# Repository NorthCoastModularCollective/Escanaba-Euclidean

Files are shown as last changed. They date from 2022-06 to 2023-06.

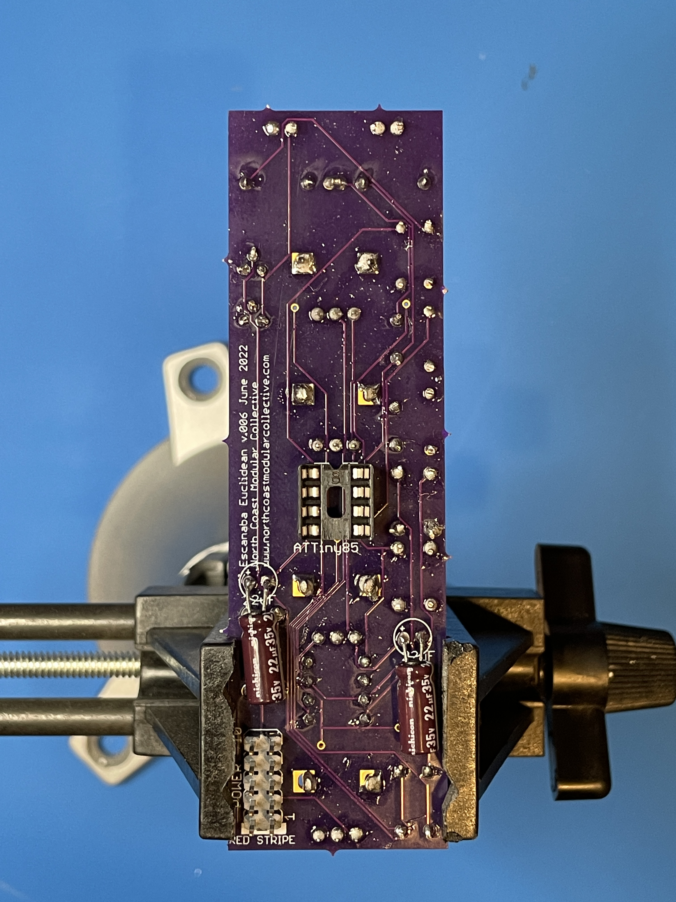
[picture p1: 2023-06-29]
build_guide/IMG_0187.JPG

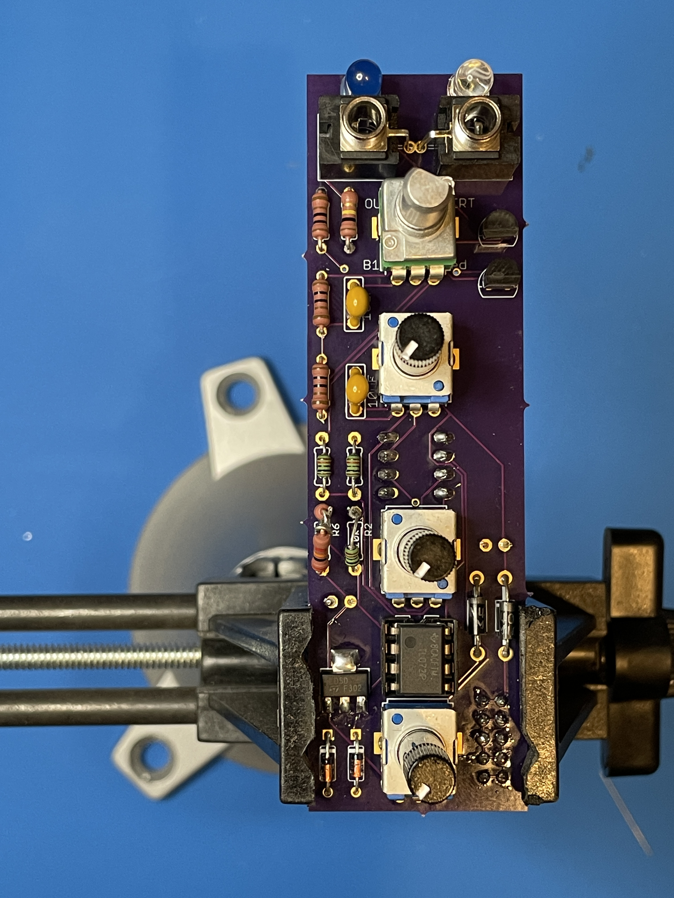
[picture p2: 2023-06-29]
build_guide/IMG_0186.JPG

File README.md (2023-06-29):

# EuclideanTrigger
A simple module, based on the ATtiny85 that creates euclidean beats from a clock input. [under development]

The Escanaba Euclidean module has 3 alternate firmware modes:
## Escanaba Euclidean Firmware 
The Eucliean firmware generates euclidean rhythms synchronized to an external eurorack clock source. If no clock source is available it will self clock. Its 3 controls are as follows: 
- Number of hits
- Length of pattern in beats
- Pattern rotation. 
When in self clocking mode, the rotation control becomes a tempo control. 
## Calumet Clock Firmware
The Calument Clock firmware turns the module into a eurorack clock source. Its 3 controls are as follows:
- Swing control
- Clock Division/Multiplication
- Tempo
## Burst Generator
The Burst Generator firmware allows the module to respond to incoming trigger signals by repeating them in a variety of ways. This allows the creation of "bouncing ball" rhythms, ratchets, and other rhythmic tricks. Its controls are as follows:
- Number of repeats
- Initial repeat speed
- A "gravity" control that controls whether the repeats accelerate or decelerate in speed.

# Build instructions

[How to build the hardware](https://github.com/NorthCoastModularCollective/Escanaba-Euclidean/wiki/Build-Instructions)

# How To Setup Firmware

1. In the Arduino editor, in the tools menu, set the board to "AtTiny25/45/85"
2. In the Arduino editor, go to Sketch->Include Library->add .zip library and then select the lib folder from the project root.
3. set Processor to "AtTiny85"
4. set Clock to "Internal 16Mhz"
6. plug your programmer into a usb port. We reccomend the (TinyAvr programmer)[https://www.sparkfun.com/products/11801] from sparkfun
7. select your programmer in the tools menu (USBTinyISP if using the TinyAvr programmer - Note: Windows needs a driver for this to work)
8. in tools, select burn bootloader. Your AtTiny is now configured to run at 16Mhz.
9. now hit the upload button in the arduino editor to flash the firmware. (Note: if you're on a Mac, select "Sketch > Upload Using Programmer" because the upload button may throw an error about no programmer being available)
10. place the chip into the mount on the back of the module. Take care to make sure the dot on the back of the chip aligns with the indent on the PCB board diagram.
11. plug the module into your rack and have fun!

# License
All works are [CC BY NC](https://creativecommons.org/licenses/by-nc/4.0/) unless otherwise specified.

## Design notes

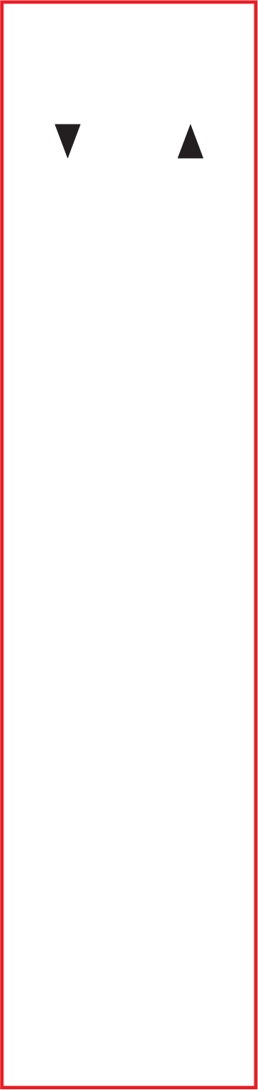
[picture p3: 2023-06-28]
hardware/panels/v12/euclidean panel v12 DiffusionLabels.BMP

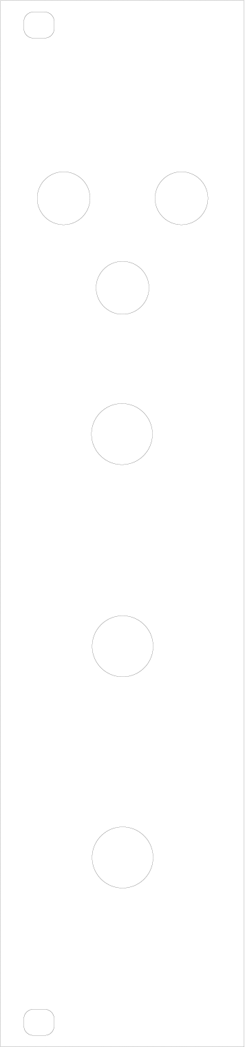
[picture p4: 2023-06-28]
hardware/panels/v12/euclidean panel v12 DrillHoles.png

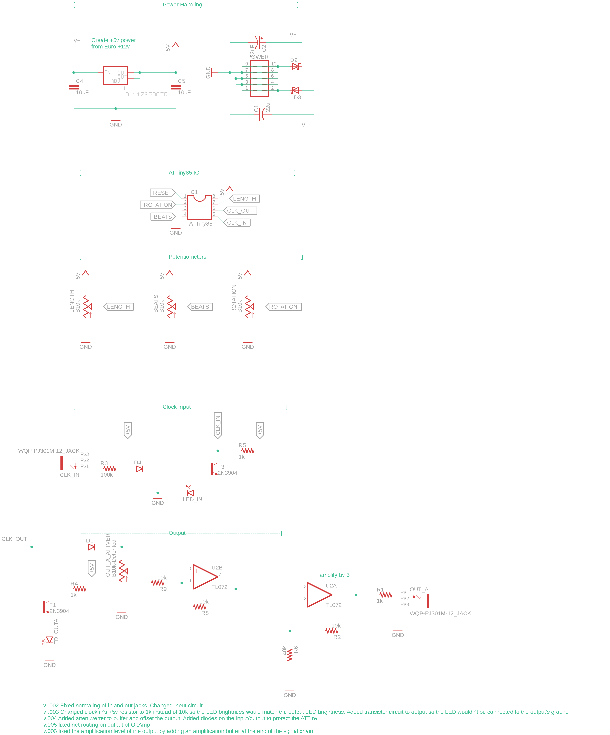
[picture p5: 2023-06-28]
hardware/PCB/Schematic.png

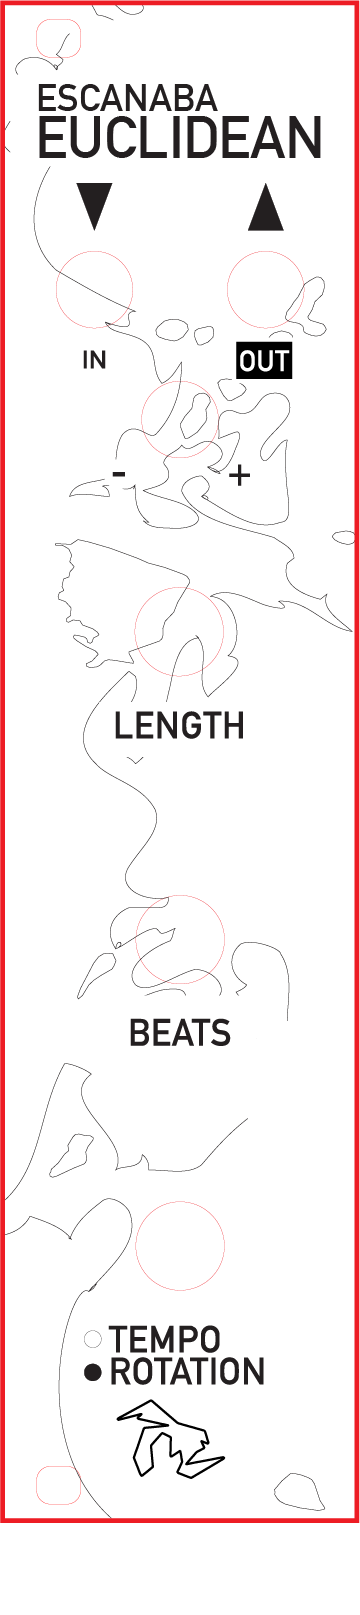
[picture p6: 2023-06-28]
hardware/panels/Escanaba Euclidean/euclidean panel v13 REFERENCE.BMP

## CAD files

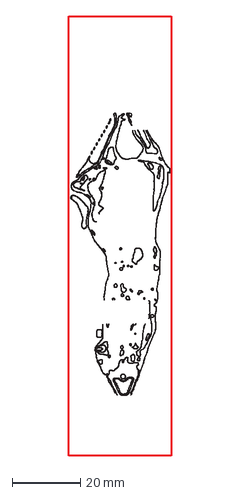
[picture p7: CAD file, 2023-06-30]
hardware/panels/Belle Isle Burst/Belle Isle Burst panel v12 TOPO LINES.dxf
30.0 x 128.5 mm

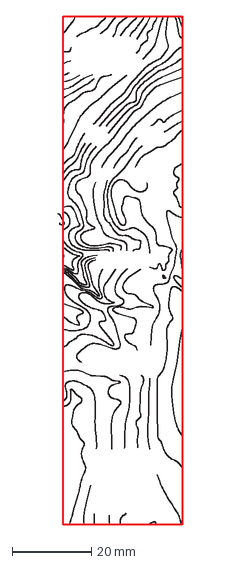
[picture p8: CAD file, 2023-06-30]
hardware/panels/Calumet Clock/Calumet Clock panel v12 TOPO LINES.dxf
31.3 x 128.5 mm

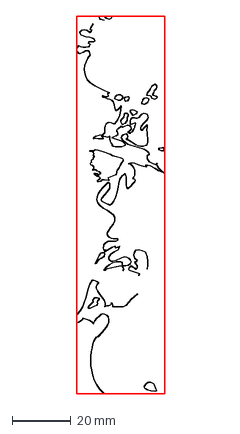
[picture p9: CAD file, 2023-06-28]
hardware/panels/v12/euclidean panel v12 TopoLines.dxf
30.5 x 128.5 mm

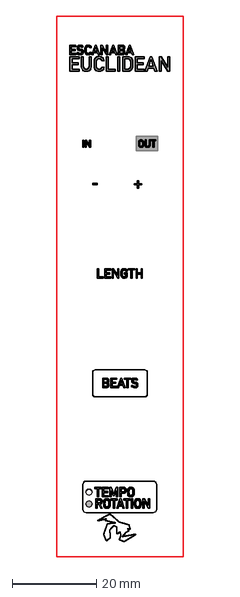
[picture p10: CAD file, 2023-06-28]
hardware/panels/v12/euclidean panel v12 PanelGraphics v2.dxf
30.0 x 128.5 mm

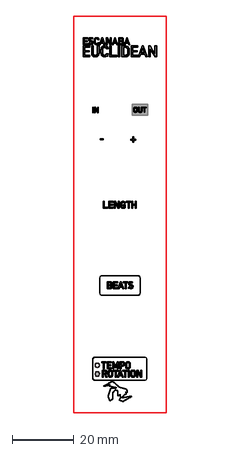
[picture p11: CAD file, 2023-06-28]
hardware/panels/v12/euclidean panel v12 PanelGraphics.dxf
30.0 x 128.5 mm

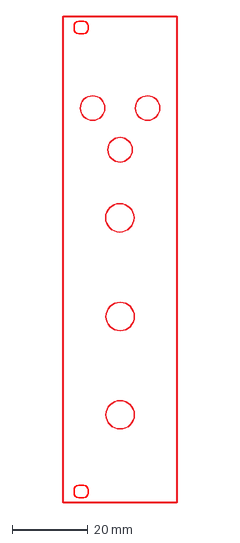
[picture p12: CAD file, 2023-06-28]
hardware/panels/v12/euclidean panel v12.dxf
30.0 x 128.5 mm

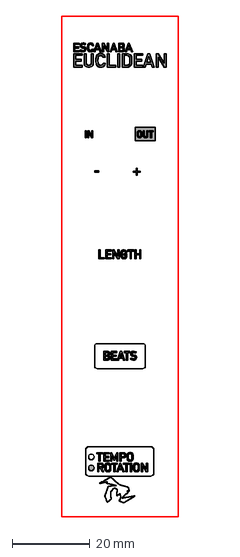
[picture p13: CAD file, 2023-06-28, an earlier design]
hardware/panels/Escanaba Euclidean/old versions/v12/euclidean panel v12.dxf
30.0 x 128.5 mm

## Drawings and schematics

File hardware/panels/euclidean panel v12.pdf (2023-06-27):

## EUCLIDEAN

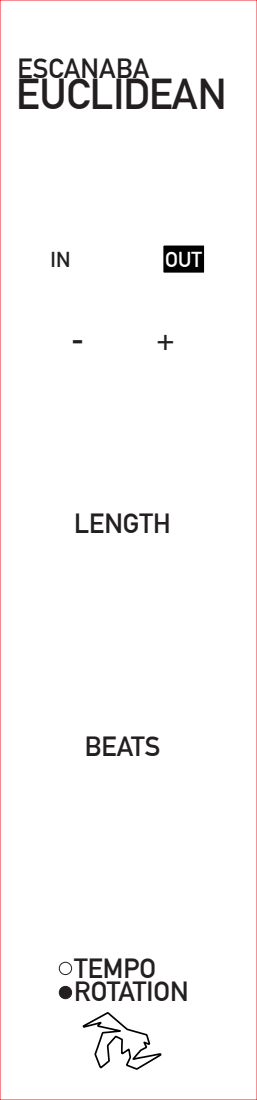
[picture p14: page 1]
OUT; LENGTH; BEATS; ROTATION; TEMPO; ESCANABA

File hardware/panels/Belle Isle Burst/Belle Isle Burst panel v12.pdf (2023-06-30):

## BURST

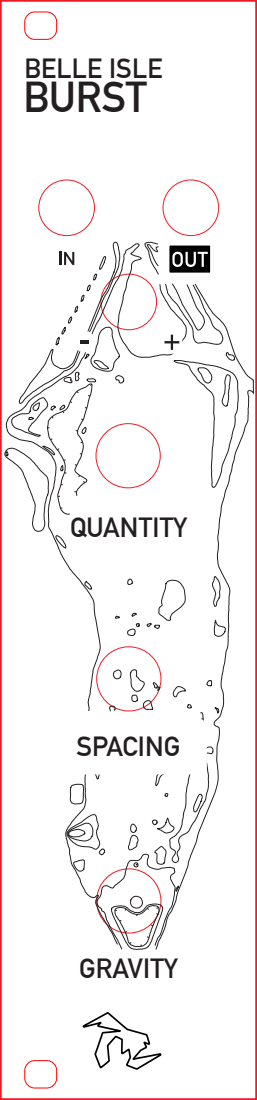
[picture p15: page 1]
QUANTITY; SPACING; GRAVITY; BELLE ISLE

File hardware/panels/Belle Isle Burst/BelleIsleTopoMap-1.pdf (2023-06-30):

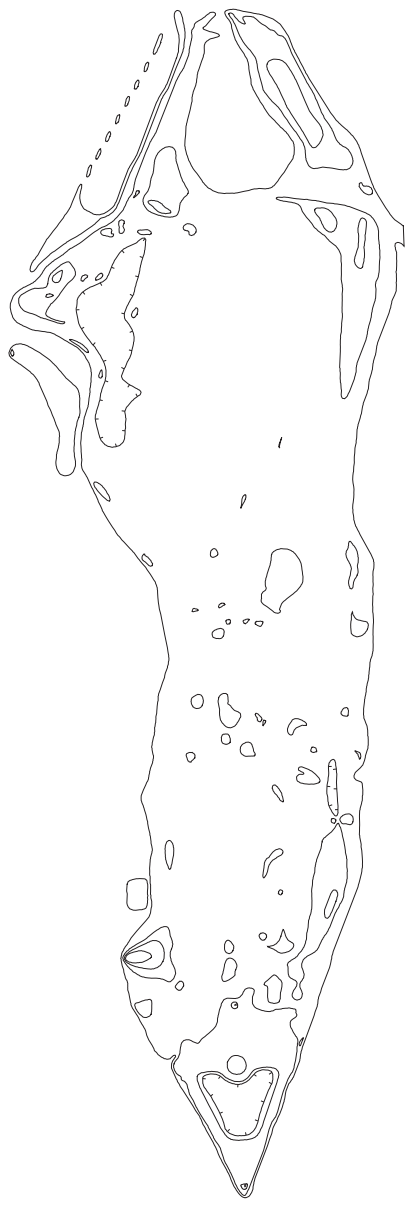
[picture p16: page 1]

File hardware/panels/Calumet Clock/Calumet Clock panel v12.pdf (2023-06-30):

## CLOCK

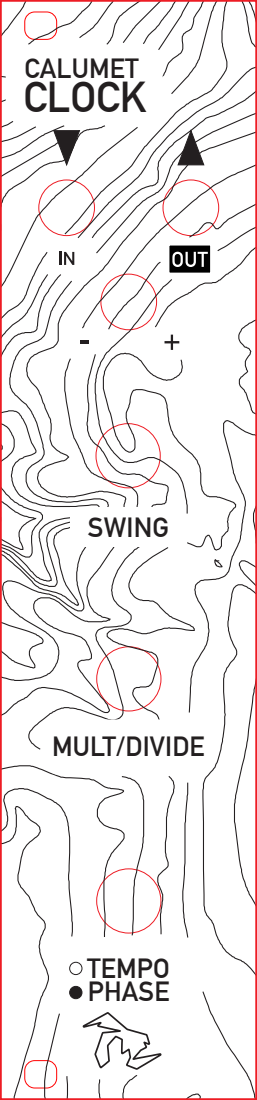
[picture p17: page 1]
SWING; MULT/DIVIDE; PHASE; TEMPO; CALUMET

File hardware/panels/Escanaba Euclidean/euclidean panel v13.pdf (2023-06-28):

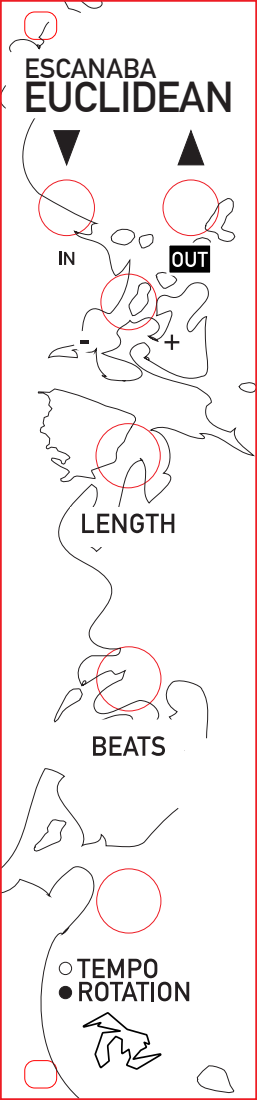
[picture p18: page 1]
ESCANABA EUCLIDEAN

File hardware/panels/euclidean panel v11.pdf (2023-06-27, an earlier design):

## EUCLIDEAN

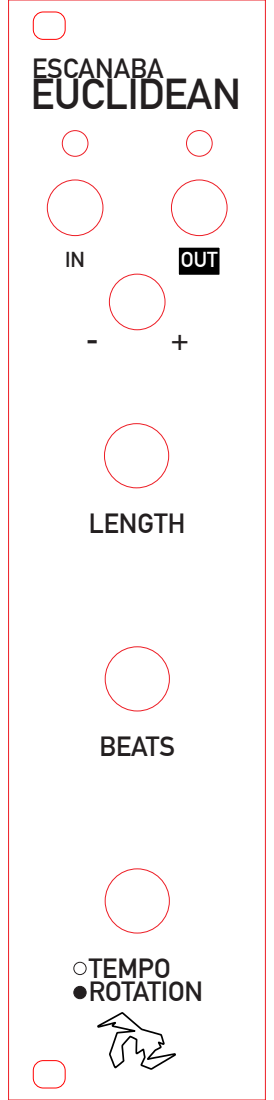
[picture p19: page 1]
OUT; LENGTH; BEATS; ROTATION; TEMPO; ESCANABA

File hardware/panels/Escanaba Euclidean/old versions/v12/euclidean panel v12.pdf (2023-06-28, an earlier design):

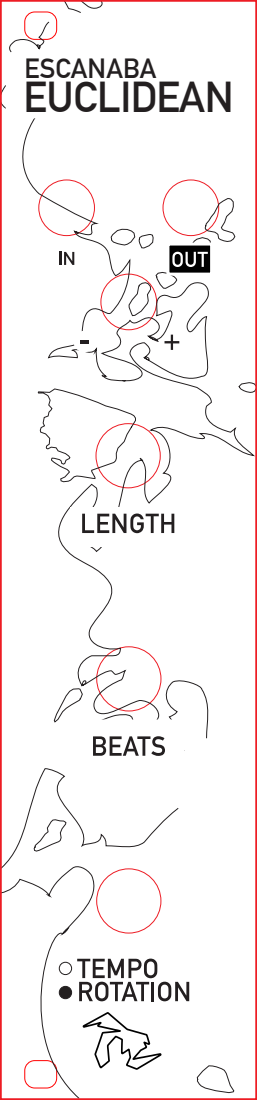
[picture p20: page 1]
ESCANABA EUCLIDEAN

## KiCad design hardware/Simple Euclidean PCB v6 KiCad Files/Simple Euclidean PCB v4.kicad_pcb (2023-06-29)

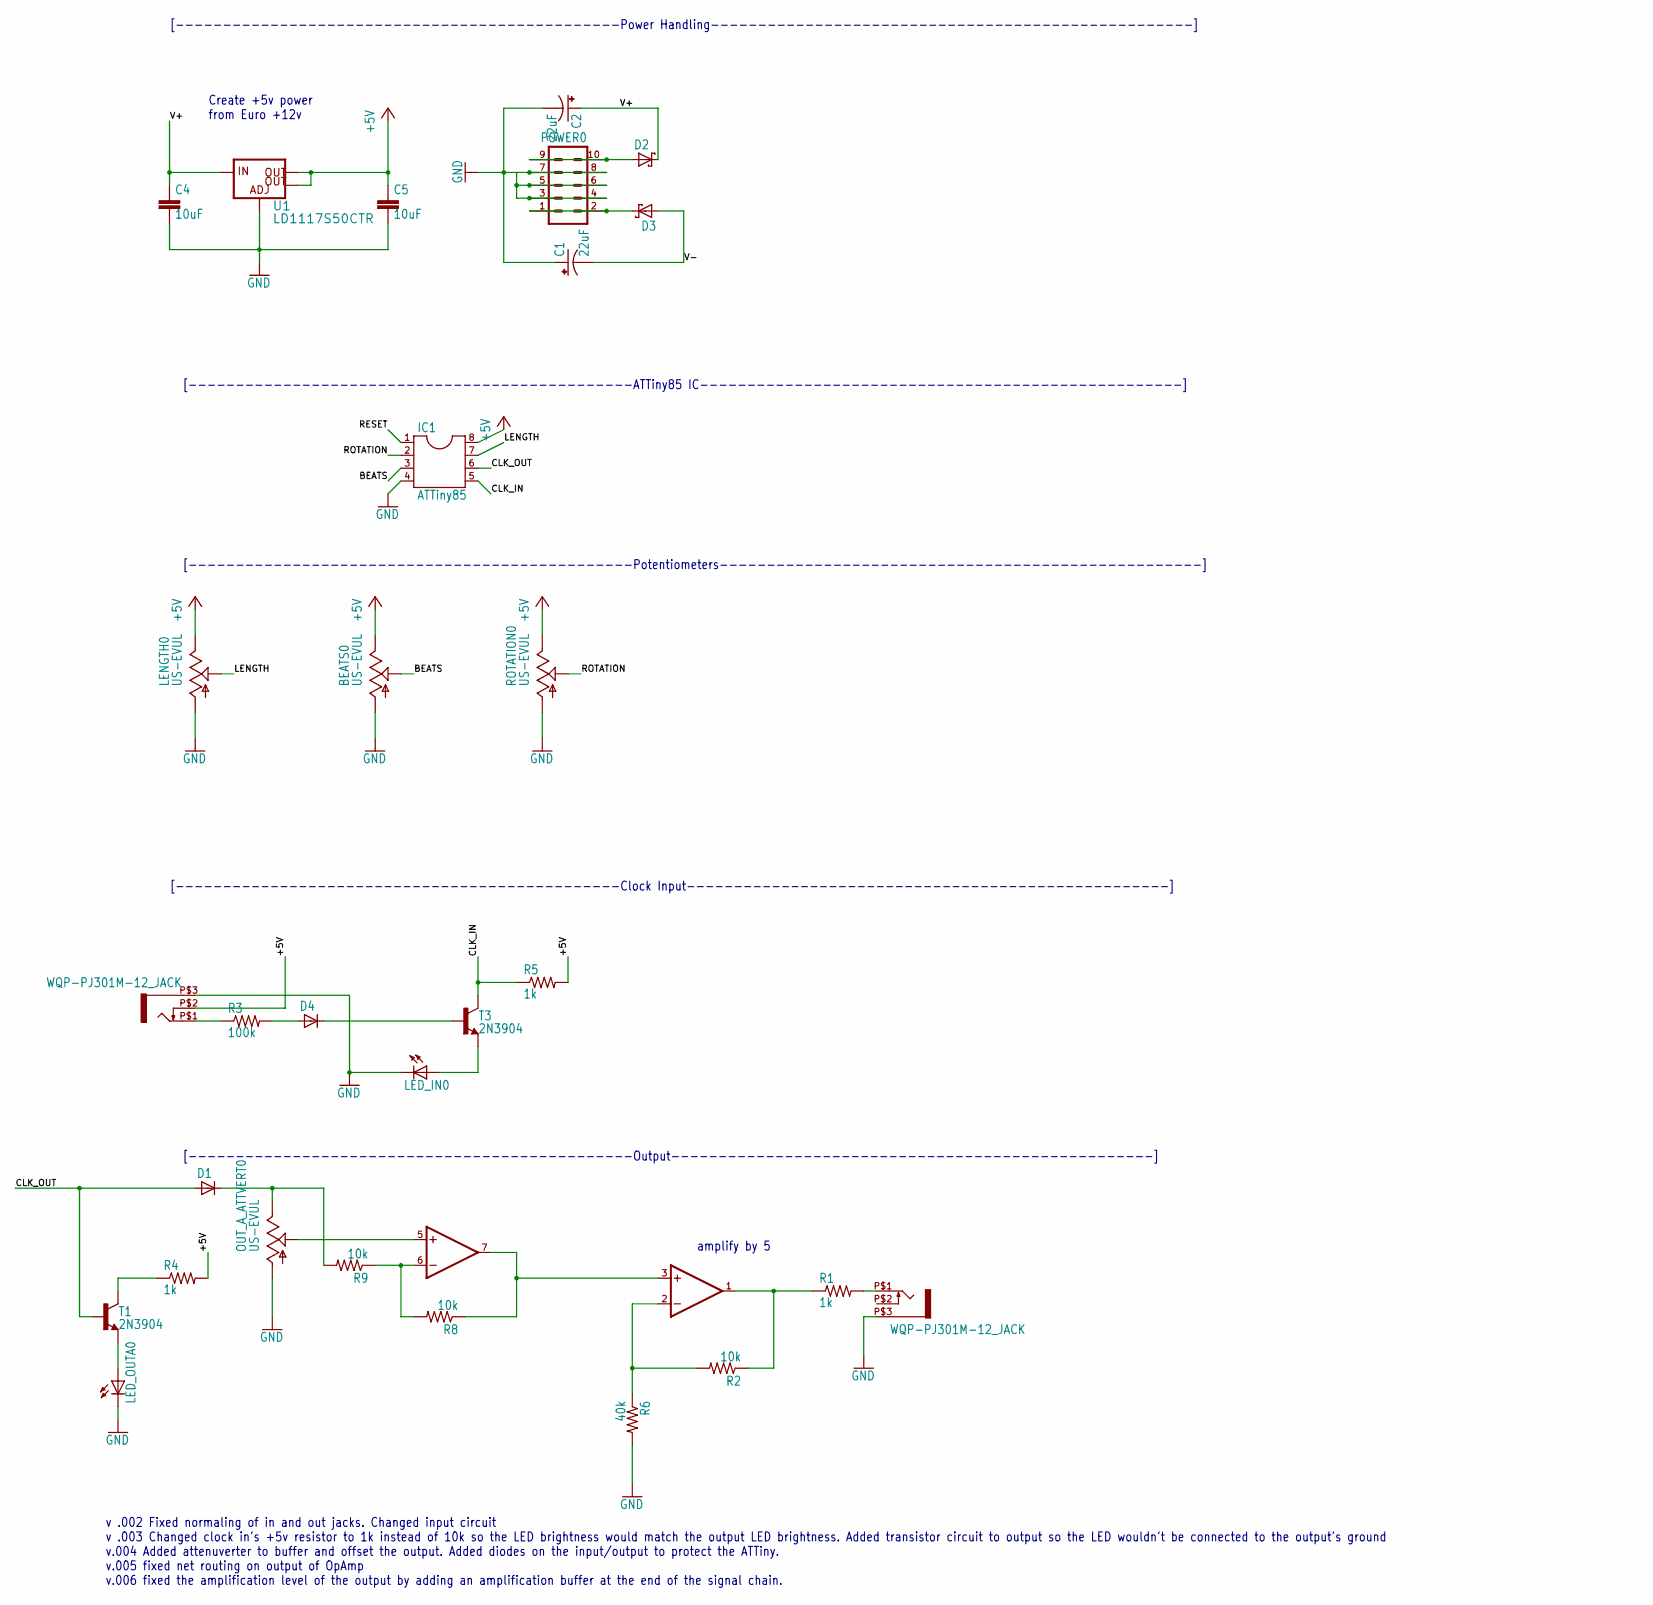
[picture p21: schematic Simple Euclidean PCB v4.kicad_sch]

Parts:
BEATS0: US-EVUL; EVUFXL
C1, C2: 22uF; E2,5-5
C4, C5: 10uF; C5B2.5
CLK_IN0: WQP-PJ301M-12_JACK
D1, D4: SMALL_DIODEDO35-7; DO35-7
D2, D3: SCHOTTKY-DIODEDO41; DO41-10
IC1: ATTiny85; DIL08
LED_IN0: LED3MM
LED_OUTA0: LED3MM
LENGTH0: US-EVUL; EVUFXL
OUT_A0: WQP-PJ301M-12_JACK
OUT_A_ATTVERT0: US-EVUL; EVUFXL
POWER0: MA05-2
R1, R4, R5: 1k; 0204_7
R2, R8, R9: 10k; 0204_7
R3: 100k; 0204_7
R6: 40k; 0204_7
ROTATION0: US-EVUL; EVUFXL
T1, T3: 2N3904; TO92
U1: LD1117S50CTR; SOT223
U2: TL072; DIL08-SML

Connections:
+5V: BEATS0.3 (E), C5.1, CLK_IN0.P$2 (3), IC1.8, LENGTH0.3 (E), R4.2, R5.2, ROTATION0.3 (E), U1.2 (OUT), U1.4 (OUT@1)
BEATS: BEATS0.2 (S), IC1.3
CLK_IN: IC1.5, R5.1, T3.1 (C)
CLK_IN1: R4.1, T1.1 (C)
CLK_OUT: D1.A, IC1.6, T1.2 (B)
GND: BEATS0.1 (A), C1.+, C2.-, C4.2, C5.2, CLK_IN0.P$3 (1), IC1.4, LED_IN0.K (C), LED_OUTA0.K (C), LENGTH0.1 (A), OUT_A0.P$3 (1), OUT_A_ATTVERT0.1 (A), POWER0.3, POWER0.4, POWER0.5, POWER0.6, POWER0.7, POWER0.8, R6.2, ROTATION0.1 (A), U1.1 (ADJ)
LENGTH: IC1.7, LENGTH0.2 (S)
unnamed: CLK_IN0.P$1 (2), R3.1
unnamed: OUT_A0.P$1 (2), R1.2
unnamed: D1.C, OUT_A_ATTVERT0.3 (E), R9.2
unnamed: D4.C, T3.2 (B)
unnamed: D4.A, R3.2
unnamed: LED_IN0.A, T3.3 (E)
unnamed: LED_OUTA0.A, T1.3 (E)
unnamed: R1.1, R2.1, U2.1 (OUT)
unnamed: R2.2, R6.1, U2.2 (-IN)
unnamed: OUT_A_ATTVERT0.2 (S), U2.5 (+IN)
unnamed: R8.2, R9.1, U2.6 (-IN)
unnamed: D2.A, POWER0.9, POWER0.10
unnamed: D3.C, POWER0.1, POWER0.2
OPAMPOUT: R8.1, U2.3 (+IN), U2.7 (OUT)
RESET: IC1.1
ROTATION: IC1.2, ROTATION0.2 (S)
V+: C2.+, C4.1, D2.C, U1.3 (IN), U2.8 (V+)
V-: C1.-, D3.A, U2.4 (V-)

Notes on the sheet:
amplify by 5
v .002 Fixed normaling of in and out jacks. Changed input circuit v .003 Changed clock in's +5v resistor to 1k instead of 10k so the LED brightness would match the output LED brightness. Added transistor circuit to output so the LED wouldn't be connected to the output's ground v.004 Added attenuver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
[-----------------------------------------------ATTiny85 IC---------------------------------------------------]
Create +5v power from Euro +12v
[-----------------------------------------------Clock Input---------------------------------------------------]
[-----------------------------------------------Power Handling---------------------------------------------------]
[-----------------------------------------------Output---------------------------------------------------]
[-----------------------------------------------Potentiometers---------------------------------------------------]

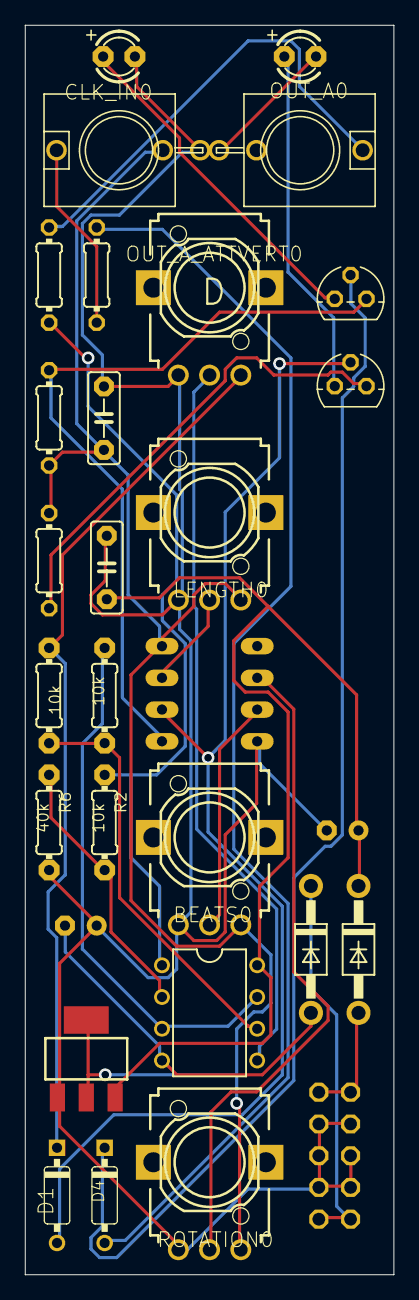
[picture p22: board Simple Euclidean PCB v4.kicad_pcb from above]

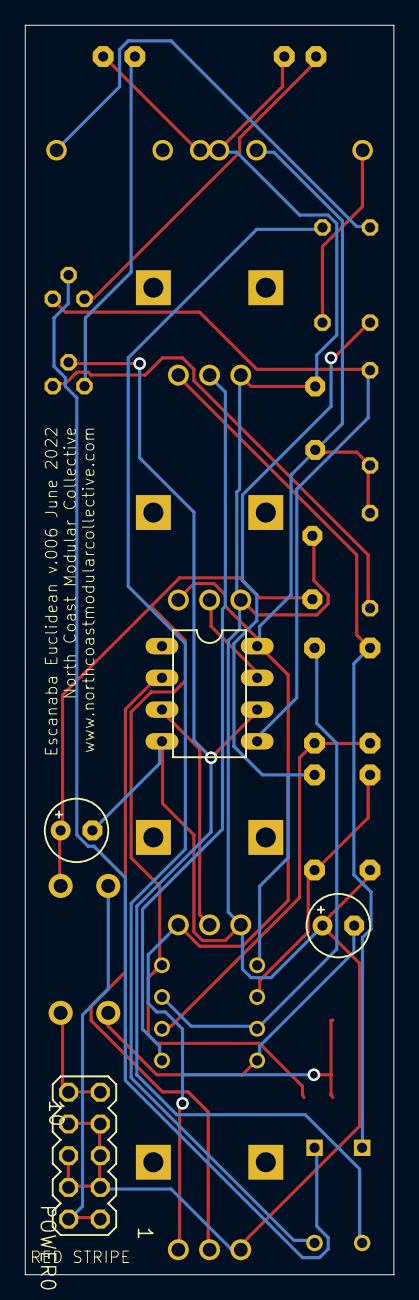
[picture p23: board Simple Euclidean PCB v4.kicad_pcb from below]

Board: 2 copper layers, 29.5 x 100.0 mm, 30 parts (4 on the bottom side), 24 nets.

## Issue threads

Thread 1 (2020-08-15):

Clock out fires a trigger on module power up

joebauer, 2020-08-15:
For some reason the module sends a trig as it is powering on. Make it so no voltages come out of the clock out unless there is a valid clock in, or unless the module is in internal clocking mode.

Note: The led output jack is normalize to the positive lead rather than the negative... verify that this is not a hardware issue.

billvanloo, 2024-01-03:
Nick and I tested this today via Zoom. We observed the following behavior:

1. When power is applied to the system, the Clock module produces at least one pulse immediately. We sometimes observed it sending out two pulses, but it was hard to distinguish whether this was based on the clock tempo or just random pulses.
2. Clock seems to immediately start up in internally clocked mode, and starts generating pulses right away at the determined clock rate.

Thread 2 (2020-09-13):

Clock output LED is dim when jack connected

joebauer, 2020-09-13:

billvanloo, 2024-01-03:
I can't reproduce this with either the Calumet Clock or Euclidean firmwares running on 2 separate builds of the modules. I think this was fixed.

Closed 2024-01-03.

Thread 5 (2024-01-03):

Internal/External Clock Modes not yet implemented

billvanloo, 2024-01-03:
Based on our observations during testing, as well as looking at the source code for Calumet Clock, @thynk and I determined that the code to switch between internal and external clock modes is not yet implemented.

There are variables defined for configuration:

const milliseconds TIME_UNTIL_INTERNAL_CLOCK_MODE = 4000;
const ClockMode CLOCK_MODE_ON_STARTUP = internal;

These don't appear anywhere else in the code yet, however. That is, there's no check that uses the TIME_UNTIL_INTERNAL_CLOCK_MODE to determine when it should switch from externally clocked to internally clocked mode, and nothing that uses the ClockMode variable to switch between internal and external.

billvanloo, 2024-01-03:
This appears to be implemented in the Euclidean firmware; there is a clockMode variable defined in Euclidean that is then used in a switch statement to determine in which mode to operate. This should probably just be copied over to Clock:

https://github.com/NorthCoastModularCollective/Escanaba-Euclidean/blob/master/EscansabaEuclidean/

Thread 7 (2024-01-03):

Output voltage too low to trigger LPG

billvanloo, 2024-01-03:
The output voltage of Clock and Euclidean is too low to correctly trigger the LPG, while the output voltage of Pam's triggers LPG correctly.

During Zoom testing today, @thynk and I observed the following:

1. Both Clock and Euclidean produced output voltages for their trigger signals in the range of -3.4V to +3.4V. Photos of the scope below.

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

2. The attenuverter works correctly, with the center detent measuring almost exactly 0V (we measured between 0.02 and 0.03V).

3. By comparison, the output from Pamela's New Workout, set to 100% level, produces a voltage of around 4.1-4.9V. Photo of the scope below.

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

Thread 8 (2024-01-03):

Output LED does not dim in proportion to attenuverter setting

billvanloo, 2024-01-03:
@thynk and I observed during testing that the output LED does not dim when the attenuverter control is adjusted. The output LED is a consistent brightness value regardless of the attenuverter's setting.

From a user perspective, it would be nice if the LED brightness was proportional to the attenuverter's setting, to show that the output signal is being reduced in level. This would probably require a bipolar LED to allow the inverted voltage to still power it correctly, which might mean a hardware revision.

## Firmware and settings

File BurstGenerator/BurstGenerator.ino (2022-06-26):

#include <clock_core.h>
#include <tuple.h>
#include <euclid_core.h>
/* CONFIG */
const milliseconds PULSE_WIDTH = 10;
const milliseconds TIME_UNTIL_INTERNAL_CLOCK_MODE = 4000;
const ClockMode CLOCK_MODE_ON_STARTUP = internal; //module starts up in internal clock mode... change this line to default the clock mode to external if needed
const unsigned short MAX_BEATS_IN_BAR = 16;

/* HARDWARE */
const int triggerOutPin           = 1;
const int triggerInPin            = 0;
const int numberOfRepeatsKnobPin  = A1;
const int spacingKnobPin          = A2;
const int gravityKnobPin          = A3;

/* GLOBAL STATE */
milliseconds timeOfLastTriggerInChange;
milliseconds timeOfLastPulseOut;
bool previousTriggerInputState = false;
unsigned int numberOfRepeatsCounter = 0;
unsigned long timeOfNextTriggerInMillis = 200;
bool isBursting = false;
unsigned int numberOfRepeats=0;
unsigned int spacingInMillis=0;


/* SHELL (global state and run loop) */
void setup()
{
  pinMode(triggerOutPin, OUTPUT);
  pinMode(triggerInPin, INPUT);
  digitalWrite(triggerOutPin, LOW);

}

void loop()
{
  const auto currentTime = millis();
  
  const unsigned int initialSpacingInMillis = readSpacingInput();
  const bool stateOfTriggerInPin = readTriggerInput();
  const float gravity = readGravityInput();
  const auto hasNewTriggerIn = detectNewRisingClockEdge(stateOfTriggerInPin, previousTriggerInputState); 
  bool shouldTrigger = false;
  if(hasNewTriggerIn){
    numberOfRepeats = readNumberRepeatsInput();
    timeOfNextTriggerInMillis = currentTime + initialSpacingInMillis;
    numberOfRepeatsCounter = 0;
    shouldTrigger = true;
    isBursting = true;
    spacingInMillis = initialSpacingInMillis;
  } else if (isBursting && numberOfRepeatsCounter<numberOfRepeats && currentTime >= timeOfNextTriggerInMillis){
    timeOfNextTriggerInMillis = currentTime + spacingInMillis;
    numberOfRepeatsCounter++;
    shouldTrigger = true;
    spacingInMillis*=gravity;
  }

  timeOfLastPulseOut = processTriggerOutput(shouldTrigger, timeOfLastPulseOut, currentTime, PULSE_WIDTH);
  previousTriggerInputState = stateOfTriggerInPin;
}

/* SHELL (IO) */

milliseconds processTriggerOutput(bool shouldTrigger, milliseconds timeOfLastPulseOut, milliseconds currentTime, milliseconds PULSE_WIDTH) {
  milliseconds timeOfPulseOutToReturn = timeOfLastPulseOut;
  if (shouldTrigger) {
    digitalWrite(triggerOutPin, HIGH);
    timeOfPulseOutToReturn = currentTime;
    shouldTrigger=false;
  } else if ((currentTime - timeOfLastPulseOut) > PULSE_WIDTH) {

    digitalWrite(triggerOutPin, LOW);
  }

  return timeOfPulseOutToReturn;
}

bool readTriggerInput() {
  return !digitalRead(triggerInPin);
}

float fmap(long x, long in_min, long in_max, float out_min, float out_max) {
  return float(x - in_min) * float(out_max - out_min) / float(in_max - in_min) + out_min;
}

unsigned int readNumberRepeatsInput(){
  // add debounce?
  return map(analogRead(numberOfRepeatsKnobPin), 0, 1023, 0, 23);  
}

unsigned int readSpacingInput(){
  // add debounce?
  return map(analogRead(spacingKnobPin), 0, 1023, 30, 2000); 
}

float readGravityInput(){
  // add debounce?
  auto input = analogRead(gravityKnobPin);
  float gravity = 1;
  if(input < 490){
    gravity = fmap(input, 0, 490, 0.6, 0.99);
  } else if (input > 526){
    gravity = fmap(input, 526, 1023, 1.01, 1.5);
  }

  return gravity;  
}

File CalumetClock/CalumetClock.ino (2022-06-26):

#include <clock_core.h>
#include <tuple.h>
#include <euclid_core.h>
/* CONFIG */
const milliseconds PULSE_WIDTH = 10;
const milliseconds TIME_UNTIL_INTERNAL_CLOCK_MODE = 4000;
const ClockMode CLOCK_MODE_ON_STARTUP = internal; //module starts up in internal clock mode... change this line to default the clock mode to external if needed
const unsigned short MAX_BEATS_IN_BAR = 16;



/* HARDWARE */
const int clockOutPin               = 1;
const int clockInPin                = 0;
const int swingKnobPin              = A1;
const int rotationKnobPin           = A3;
const int clockSpeedModifierKnobPin = A2;

/* GLOBAL STATE */
milliseconds timeOfLastClockInChange;
milliseconds timeOfLastPulseOut;
InternalClock internalClock  = InternalClock {false, 0, 133,false};
ClockMultiplyDivideRanges clockSpeedModifier = ONE;
float swingAmount=0;

/* SHELL (global state and run loop) */

void setup()
{
  pinMode(clockOutPin, OUTPUT);
  pinMode(clockInPin, INPUT);
  digitalWrite(clockOutPin, LOW);

}

void loop()
{

  milliseconds currentTime = millis();

  bool stateOfClockInPin = readClockInput();
  clockSpeedModifier = readClockSpeedModifier();
  swingAmount = readSwingInput();
  internalClock.basePeriod = convertBPMToPeriodInMillis(readTempoInput());
  
  bool previousInternalClockState = internalClock.isClockHigh;

  internalClock = updateInternalClock(currentTime, internalClock, clockSpeedModifier, swingAmount);
  bool shouldTrigger = detectNewRisingClockEdge(internalClock.isClockHigh, previousInternalClockState);
      
  timeOfLastPulseOut = processTriggerOutput(shouldTrigger, timeOfLastPulseOut, currentTime, PULSE_WIDTH);

}

/* SHELL (IO) */

milliseconds processTriggerOutput(bool shouldTrigger, milliseconds timeOfLastPulseOut, milliseconds currentTime, milliseconds PULSE_WIDTH) {
  milliseconds timeOfPulseOutToReturn = timeOfLastPulseOut;
  if (shouldTrigger) {
    digitalWrite(clockOutPin, HIGH);
    timeOfPulseOutToReturn = currentTime;
    shouldTrigger=false;
  } else if ((currentTime - timeOfLastPulseOut) > PULSE_WIDTH) {

    digitalWrite(clockOutPin, LOW);
  }
  return timeOfPulseOutToReturn;
}

bool readClockInput() {
  return !digitalRead(clockInPin);
}

unsigned int readTempoInput(){
  // add debounce?
  int inputFromRotationPin = analogRead(rotationKnobPin);
  return mapTempoInputToTempoInBpm(inputFromRotationPin);  
}

float fmap(long x, long in_min, long in_max, float out_min, float out_max) {
  return (x - in_min) * (out_max - out_min) / (in_max - in_min) + out_min;
}

float readSwingInput(){
  // add debounce?
  int input = analogRead(swingKnobPin);

  float swing = 0;
  if(input < 490){
    swing = fmap(input, 0, 490, -0.8, 0);
  } else if (input > 526){
    swing = fmap(input, 526, 1023, 0, 0.8);
  }
  return swing;
}



ClockMultiplyDivideRanges mapClockSpeedModifierInputToEnumValue(int inputFromPin){
  float stepSize = 1024.0/__SIZE__;
 // static_cast<ClockMultiplyDivideRanges>(floor(inputFromPin/stepSize));

  if(inputFromPin<stepSize){
    return EIGHT_DIV;
  } 
  else if(inputFromPin<stepSize*2){
    return FOUR_DIV;
  }
  else if(inputFromPin<stepSize*3){
    return THREE_DIV;
  }
  else if(inputFromPin<stepSize*4){
    return TWO_DIV;
  }
  else if(inputFromPin<stepSize*5){
    return ONE_POINT_FIVE_DIV;
  }
  else if(inputFromPin<stepSize*6){
    return ONE;
  }
  else if(inputFromPin<stepSize*7){
    return ONE_POINT_FIVE_MULT;
  }
  else if(inputFromPin<stepSize*8){
    return TWO_MULT;
  }
  else if(inputFromPin<stepSize*9){
    return THREE_MULT;
  }
  else if(inputFromPin<stepSize*10){
    return FOUR_MULT;
  }
  else if(inputFromPin<stepSize*11){
    return EIGHT_MULT;
  }
}

ClockMultiplyDivideRanges readClockSpeedModifier(){
  // add debounce?
  int inputFromPin = analogRead(clockSpeedModifierKnobPin);
  return mapClockSpeedModifierInputToEnumValue(inputFromPin);  
}

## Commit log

2020-06-20 First version - hello world with an LED
2020-06-28 Updated button schematic. Added IF logic.
    In this version, the test LED goes on once but only once. Should keep going on every time the button is pressed.
2020-08-29 it appears i was overzealous... it still needs to be in a sketch folder for arduino ide
2020-09-13 oops... i had moved the set for previous trigger input state to earlier in the loop and it broke external clock mode... here is the fix
    [EscansabaEuclidean.ino]
2021-07-02 timer interrupt was wrong... making it turn on once as a debugging step
    [EscansabaEuclidean.ino]
2021-07-03 playing with interrupt subdivision... need to run more tests
2021-07-03 removing interrupt code to get back to known working state... further interrupt experiments will happen on a branch
2021-07-03 clock mode switch is more clearly labled
2021-07-30 external clock mode is broken... internal clock has basic functionality
    [CalumetClock.ino]
2022-06-26 added schematic
2023-06-27 Added V12 of the Euclidean Panel
    Added V12 of the Euclidean Panel, and exported 3 separate layers for panel creation in KiCad.
2023-06-27 Create euclidean panel v12 DrillHoles v3.svg
    updated with only one layer
2023-06-28 Create euclidean panel v12 DrillHoles.png
2023-06-28 Create euclidean panel v12 DrillHoles.BMP
2023-06-28 Create euclidean panel v12.dxf
    [euclidean panel v12.dxf]
2023-06-28 Create euclidean panel v12 PanelGraphics.dxf
    [euclidean panel v12 PanelGraphics.dxf]
2023-06-28 Update euclidean panel v12 PanelGraphics.dxf
    [euclidean panel v12 PanelGraphics.dxf]
2023-06-28 outlined text in Illustrator before export
    [euclidean panel v12 PanelGraphics.dxf]
2023-06-28 Tried export as DXF 2000
    [euclidean panel v12 PanelGraphics v2.dxf]
2023-06-28 Create euclidean panel v12 TopoLines.dxf
    [euclidean panel v12 TopoLines.dxf]
2023-06-28 Added folders for each of the module variations
    Added folders for each of the module variations, reorganized files to make each version have its own discrete folder.
    [euclidean panel v12 PanelGraphics v2.dxf, euclidean panel v12 PanelGraphics.dxf, euclidean panel v12 TopoLines.dxf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]
2023-06-28 added gerbers
2023-06-28 Updated schematics and gerbers
2023-06-29 Added SMD and Diodes images.
2023-06-29 socket and cap img
2023-06-29 power header img
2023-06-29 added KiCad fiels
    [Clock and Burst Panel.kicad_pcb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]
2023-06-30 Updated topo lines, exported as DXF for import to KiCad
    Updated topo lines, exported as DXF for import to KiCad
    [Belle Isle Burst panel v12 TOPO LINES.dxf, Calumet Clock panel v12 TOPO LINES.dxf]
